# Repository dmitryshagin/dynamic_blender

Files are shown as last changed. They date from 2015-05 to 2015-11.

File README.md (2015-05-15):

# Dynamic trimix blender 
**This project includes both hardware description & all needed software and firmware.**

Blender is built to mix EAN and Trimix mixtures dynamically, with no more than 40% of oxygen.

Main electronic components:
* MCU: Atmega64. 16 or 32kB versions could be used with no/minimum code changes (untested).
* ADC: AD7793. Used to get accurate O2 readings.
* Any oxygen sensors with 7-25mV @ 21% O2 output could be used without any changes.

Software needed to work with schematic and board:
* [Eagle](http://www.cadsoftusa.com/download-eagle/) for schematic and board. Free version is enough.
* [FreeRouting](http://www.freerouting.net/) - was used for initial routing. Optional.
* [Gerbv](http://gerbv.sourceforge.net/) to preview gerbers. Optional - just to control them before factory processing.

I've ordered PCB's at [SeeedStudio](http://www.seeedstudio.com/service/index.php?r=pcb), but feel free to use any PCB factory with equivalent capabilities. Board size is 44x122mm.

Developed by [DiveTeam](http://diveteam.com.ua) :rowboat:

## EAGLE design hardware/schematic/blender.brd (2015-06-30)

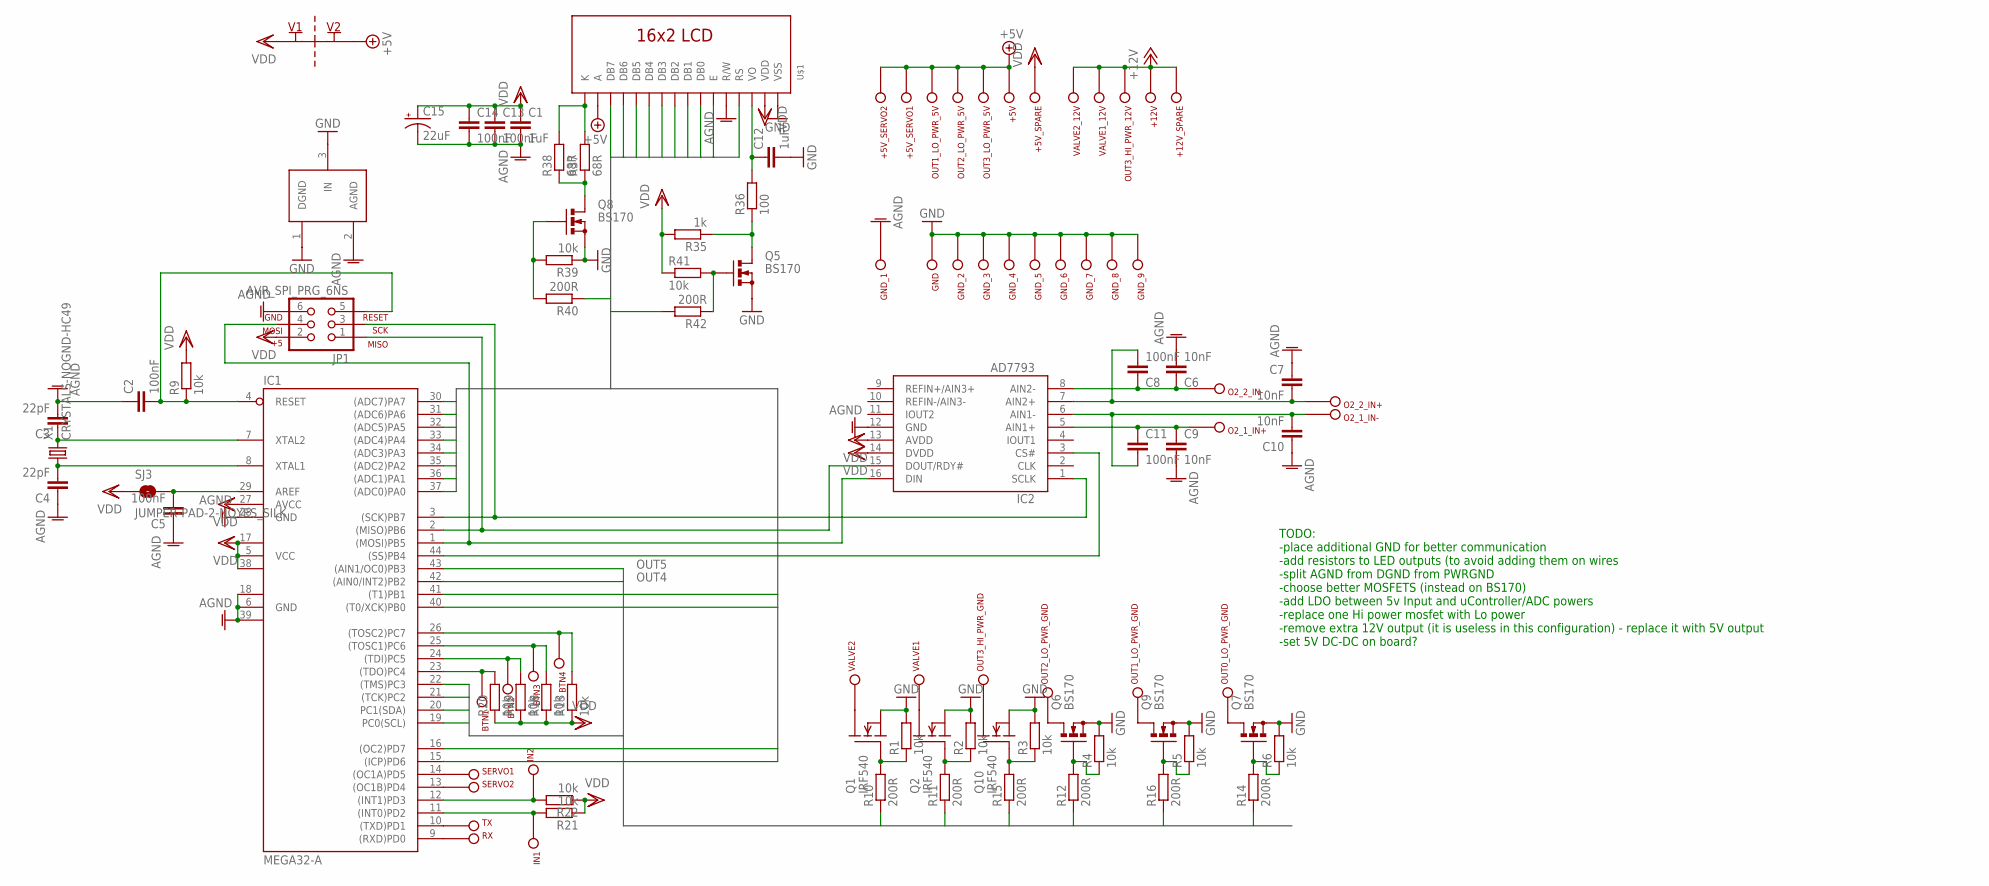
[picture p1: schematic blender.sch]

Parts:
+5V, +5V_SERVO1, +5V_SERVO2, +5V_SPARE, +12V, +12V_SPARE: PIN
BTN1, BTN2, BTN3, BTN4: PIN
C1, C12: 1uF; C0603
C2, C5, C8, C11, C13, C14: 100nF; C0603
C3, C4: 22pF; C0603
C6, C7, C9, C10: 10nF; C0603
C15: 22uF; EIA7343
GND: PIN
GND_1, GND_2, GND_3, GND_4, GND_5, GND_6, GND_7, GND_8, GND_9: PIN
IC1: MEGA32-A; TQFP44
IC2: AD7793; TSSOP16
IN1, IN2: PIN
JP1: AVR_SPI_PRG_6NS; 2X3-NS
O2_1_IN+, O2_1_IN-, O2_2_IN+, O2_2_IN-: PIN
OUT0_LO_PWR_GND, OUT1_LO_PWR_5V, OUT1_LO_PWR_GND, OUT2_LO_PWR_5V, OUT2_LO_PWR_GND, OUT3_HI_PWR_12V, OUT3_HI_PWR_GND, OUT3_LO_PWR_5V: PIN
Q1, Q2, Q10: IRF540; TO220
Q5, Q6, Q7, Q8, Q9: BS170; SOT54E
R1, R2, R3, R4, R5, R6, R9, R13, R18, R19, R20, R21, R22, R39, R41: 10k; R0603
R10, R11, R12, R14, R15, R16, R40, R42: 200R; R0603
R35: 1k; R0603
R36: 100; R0603
R37, R38: 68R; R1206
RX: PIN
SERVO1, SERVO2: PIN
SJ3: JUMPER-PAD-2-NOYES_SILK; PAD-JUMPER-2-NO_YES_SILK
TX: PIN
U$1: 1602L
U$2: SUPPLY_CONNECT; 2PT_GND_TIE
U$3: GND_CONNECT
VALVE1, VALVE1_12V, VALVE2, VALVE2_12V: PIN
X1: CRYSTALS-NOGND-HC49; HC49

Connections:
+5V: +5V.P$1, +5V_SERVO1.P$1, +5V_SERVO2.P$1, OUT1_LO_PWR_5V.P$1, OUT2_LO_PWR_5V.P$1, OUT3_LO_PWR_5V.P$1, U$1.P$15 (A), U$2.P$2
+12V: +12V.P$1, +12V_SPARE.P$1, OUT3_HI_PWR_12V.P$1, VALVE1_12V.P$1, VALVE2_12V.P$1
AGND: C1.2, C2.1, C3.2, C4.1, C5.1, C6.2, C7.1, C9.2, C10.1, C13.2, C14.2, C15.C (-), GND_1.P$1, IC1.6 (GND), IC1.18 (GND1), IC1.28 (GND), IC1.39 (GND2), IC2.12 (GND), JP1.6, U$1.P$5 (R/W), U$3.2 (AGND)
BACKLIGHT: IC1.16 ((OC2)PD7), R40.1
CONTRAST: IC1.15 ((ICP)PD6), R42.2
DB0: IC1.37 ((ADC0)PA0), U$1.P$7 (DB0)
DB1: IC1.36 ((ADC1)PA1), U$1.P$8 (DB1)
DB2: IC1.35 ((ADC2)PA2), U$1.P$9 (DB2)
DB3: IC1.34 ((ADC3)PA3), U$1.P$10 (DB3)
DB4: IC1.33 ((ADC4)PA4), U$1.P$11 (DB4)
DB5: IC1.32 ((ADC5)PA5), U$1.P$12 (DB5)
DB6: IC1.31 ((ADC6)PA6), U$1.P$13 (DB6)
DB7: IC1.30 ((ADC7)PA7), U$1.P$14 (DB7)
E: IC1.40 ((T0/XCK)PB0), U$1.P$6 (E)
GND: C12.2, GND.P$1, GND_2.P$1, GND_3.P$1, GND_4.P$1, GND_5.P$1, GND_6.P$1, GND_7.P$1, GND_8.P$1, GND_9.P$1, Q1.3 (S), Q2.3 (S), Q5.S, Q6.S, Q7.S, Q8.S, Q9.S, Q10.3 (S), R1.2, R2.2, R3.2, R4.2, R5.2, R6.2, R39.1, U$1.P$1 (VSS), U$3.1 (DGND), U$3.3 (IN)
unnamed: Q5.D, R35.1, R36.1
unnamed: C12.1, R36.2, U$1.P$3 (VO)
unnamed: Q8.D, R37.1, R38.1
unnamed: R37.2, R38.2, U$1.P$16 (K)
unnamed: Q8.G, R39.2, R40.2
unnamed: IC1.1 ((MOSI)PB5), IC2.16 (DIN), JP1.4
unnamed: IC1.2 ((MISO)PB6), IC2.15 (DOUT/RDY#), JP1.1
unnamed: IC1.3 ((SCK)PB7), IC2.1 (SCLK), JP1.3
unnamed: IC1.44 ((SS)PB4), IC2.3 (CS#)
unnamed: C2.2, IC1.4 (RESET), JP1.5, R9.1
unnamed: Q5.G, R41.2, R42.1
unnamed: C3.1, IC1.7 (XTAL2), X1.2
unnamed: C4.2, IC1.8 (XTAL1), X1.1
unnamed: Q1.1 (G), R1.1, R10.2
unnamed: Q2.1 (G), R2.1, R11.2
unnamed: Q10.1 (G), R3.1, R15.2
unnamed: BTN3.P$1, IC1.25 ((TOSC1)PC6), R18.2
unnamed: Q7.G, R6.1, R14.2
unnamed: Q6.G, R4.1, R12.2
unnamed: Q9.G, R5.1, R16.2
unnamed: C5.2, IC1.29 (AREF), SJ3.2
unnamed: IC1.12 ((INT1)PD3), IN2.P$1, R22.2
unnamed: IC1.11 ((INT0)PD2), IN1.P$1, R21.2
unnamed: BTN4.P$1, IC1.26 ((TOSC2)PC7), R13.2
unnamed: BTN2.P$1, IC1.24 ((TDI)PC5), R19.2
unnamed: BTN1.P$1, IC1.23 ((TDO)PC4), R20.2
unnamed: IC1.9 ((RXD)PD0), RX.P$1
unnamed: IC1.10 ((TXD)PD1), TX.P$1
unnamed: IC1.14 ((OC1A)PD5), SERVO1.P$1
unnamed: IC1.13 ((OC1B)PD4), SERVO2.P$1
unnamed: Q2.2 (D), VALVE1.P$1
unnamed: Q1.2 (D), VALVE2.P$1
unnamed: OUT3_HI_PWR_GND.P$1, Q10.2 (D)
unnamed: OUT0_LO_PWR_GND.P$1, Q7.D
unnamed: OUT1_LO_PWR_GND.P$1, Q9.D
unnamed: OUT2_LO_PWR_GND.P$1, Q6.D
unnamed: C10.2, C11.2, IC2.6 (AIN1-), O2_1_IN-.P$1
unnamed: C7.2, C8.2, IC2.7 (AIN2+), O2_2_IN+.P$1
unnamed: C6.1, C8.1, IC2.8 (AIN2-), O2_2_IN-.P$1
unnamed: C9.1, C11.1, IC2.5 (AIN1+), O2_1_IN+.P$1
OUT0: IC1.19 (PC0(SCL)), R14.1
OUT1: IC1.20 (PC1(SDA)), R16.1
OUT2: IC1.21 ((TCK)PC2), R12.1
OUT3: IC1.22 ((TMS)PC3), R15.1
OUT4: IC1.42 ((AIN0/INT2)PB2), R11.1
OUT5: IC1.43 ((AIN1/OC0)PB3), R10.1
RS: IC1.41 ((T1)PB1), U$1.P$4 (RS)
VDD: +5V_SPARE.P$1, C1.1, C13.1, C14.1, C15.A (+), IC1.5 (VCC), IC1.17 (VCC1), IC1.27 (AVCC), IC1.38 (VCC2), IC2.13 (AVDD), IC2.14 (DVDD), JP1.2, R9.2, R13.1, R18.1, R19.1, R20.1, R21.1, R22.1, R35.2, R41.1, SJ3.1, U$1.P$2 (VDD), U$2.P$1

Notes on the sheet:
TODO: -place additional GND for better communication -add resistors to LED outputs (to avoid adding them on wires -split AGND from DGND from PWRGND -choose better MOSFETS (instead on BS170) -add LDO between 5v Input and uController/ADC powers -replace one Hi power mosfet with Lo power -remove extra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

Board: 2 copper layers, 100 parts (44 on the bottom side), 63 nets, no tracks yet.

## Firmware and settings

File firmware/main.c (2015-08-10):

#include "adc.h"
#include "init.h"
#include "menu.h"
#include "uart_proto.h"

int main(void){
	init();	
    
	for(;;){
		process_uart();
        process_adc_data(); 
	    process_menu_selection();

		if(need_input()){
			process_menu_internal();
			reset_need_input();
		}

		if( current_working_mode != MODE_EMERGENCY ){
        	process_alert();
        }
    }
    return 0;
}

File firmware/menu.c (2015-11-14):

#include "menu.h"
#include <stdio.h>
#include <string.h>
#include <avr/io.h>
#include <util/delay.h>
#include "init.h"
#include "lcd.h"


uint8_t mixing_submenu, mode_setup_iteration, valve1_test, valve2_test;
int8_t submenu_position = -1;
int8_t last_submenu_position = -1;

volatile uint16_t current_timer_mark = 0;
volatile uint8_t countdown_timer = 0;


void set_countdown_timer(uint8_t seconds){
    current_timer_mark = get_uptime_seconds()+seconds;
}

uint8_t get_seconds_left(){
    if( current_timer_mark > get_uptime_seconds()){
        return current_timer_mark - get_uptime_seconds();
    }else{
        return 0;
    }
}


void process_buttons()
{
    if(BUTTON_PLUS_PRESSED){
        if(buttons.buttonPlus < 0xFF){
            buttons.buttonPlus+=0xF;
        }
    }else{
        buttons.buttonPlus=0;
    }
    if(BUTTON_MINUS_PRESSED){
        if(buttons.buttonMinus < 0xFF){
            buttons.buttonMinus+=0xF;
        }
    }else{
        buttons.buttonMinus=0;
    }
}

void show_run_test(){
    submenu_position = 5; //to work with UART correctly
    last_submenu_position = 5;
    current_working_mode = MODE_RUN_TEST;
    VALVE1_OFF;
    VALVE2_OFF;
    LED_VAVLE1_OFF;
    LED_VAVLE2_OFF;
    LCDGotoXY(0,0);
    LCDstring((uint8_t *)"    Run Test   >",16);
    LCDGotoXY(0,1);
    LCDstring((uint8_t *)"                ",16);
}

void show_start_calibrate(){
    current_working_mode = MODE_START_CALIBRATE;
    VALVE1_OFF;
    VALVE2_OFF;
    LED_VAVLE1_OFF;
    LED_VAVLE2_OFF;
    LCDGotoXY(0,0);
    LCDstring((uint8_t *)"   Calibrate   >",16);
    LCDGotoXY(0,1);
    LCDstring((uint8_t *)"                ",16);    
}

void show_set_o2(){
    current_working_mode = MODE_SET_O2;
    VALVE1_OFF;
    VALVE2_OFF;
    LED_VAVLE1_OFF;
    LED_VAVLE2_OFF;
    set_alert(0,0);
    set_servo(SERVO1, 0);
    set_servo(SERVO2, 0);
    LCDGotoXY(0,0);
    LCDstring((uint8_t *)"O2<  Oxygen    +",16);
    LCDGotoXY(0,1);
    LCDstring((uint8_t *)"He             -",16);
}

void show_set_he(){
    current_working_mode = MODE_SET_HE;
    VALVE1_OFF;
    VALVE2_OFF;
    LED_VAVLE1_OFF;
    LED_VAVLE2_OFF;
    LCDGotoXY(0,0);
    LCDstring((uint8_t *)"O2   Helium    +",16);
    LCDGotoXY(0,1);
    LCDstring((uint8_t *)"He<            -",16);
}

void show_set_brightness(){
    current_working_mode = MODE_SET_BRIGHTNESS;
    VALVE1_OFF;
    VALVE2_OFF;
    LED_VAVLE1_OFF;
    LED_VAVLE2_OFF; 
    LCDGotoXY(0,0);
    LCDstring((uint8_t *)"  Brightness   +",16);
    LCDGotoXY(0,1);
    LCDstring((uint8_t *)"               -",16);
}

void show_set_contrast(){
    current_working_mode = MODE_SET_CONTRAST;
    VALVE1_OFF;
    VALVE2_OFF;
    LED_VAVLE1_OFF;
    LED_VAVLE2_OFF;
    LCDGotoXY(0,0);
    LCDstring((uint8_t *)"    Contrast   +",16);
    LCDGotoXY(0,1);
    LCDstring((uint8_t *)"               -",16);
}

void show_set_emergency_level(){
    current_working_mode = MODE_SET_EMERGENCY_LEVEL;
    VALVE1_OFF;
    VALVE2_OFF;
    LED_VAVLE1_OFF;
    LED_VAVLE2_OFF;
    LCDGotoXY(0,0);
    LCDstring((uint8_t *)"  Emergency O2 +",16);
    LCDGotoXY(0,1);
    LCDstring((uint8_t *)"               -",16);
}

void show_set_valve1(){
    current_working_mode = MODE_SET_VALVE1;
    VALVE1_ON;
    VALVE2_OFF;
    LED_VAVLE1_ON;
    LED_VAVLE2_OFF;
    LCDGotoXY(0,0);
    LCDstring((uint8_t *)"  Set O2 valve +",16);
    LCDGotoXY(0,1);
    LCDstring((uint8_t *)"               -",16);
}

void show_set_valve2(){
    current_working_mode = MODE_SET_VALVE2;
    VALVE1_OFF;
    VALVE2_ON;
    LED_VAVLE1_OFF;
    LED_VAVLE2_ON;
    LCDGotoXY(0,0);
    LCDstring((uint8_t *)"  Set He valve +",16);
    LCDGotoXY(0,1);
    LCDstring((uint8_t *)"               -",16);
}

void show_set_pid(uint8_t show_max_value){
    current_working_mode = MODE_SET_PID;
    VALVE1_OFF;
    VALVE2_OFF;
    LED_VAVLE1_OFF;
    LED_VAVLE2_OFF; 
    LCDGotoXY(0,0);
    if(show_max_value){
        LCDstring((uint8_t *)"PID setup MAX  +",16);
    }else{
        LCDstring((uint8_t *)"PID setup x128 +",16);    
    }
    LCDGotoXY(0,1);
    LCDstring((uint8_t *)"               -",16);
}

void show_set_servo1_min(){
    current_working_mode = MODE_SET_SERVO1_MIN;
    VALVE1_ON;
    VALVE2_OFF;
    LED_VAVLE1_ON;
    LED_VAVLE2_OFF; 
    LCDGotoXY(0,0);
    LCDstring((uint8_t *)"  Servo1 MIN   +",16);
    LCDGotoXY(0,1);
    LCDstring((uint8_t *)"               -",16);
}

void show_set_servo1_max(){
    current_working_mode = MODE_SET_SERVO1_MAX;
    VALVE1_ON;
    VALVE2_OFF;
    LED_VAVLE1_ON;
    LED_VAVLE2_OFF; 
    LCDGotoXY(0,0);
    LCDstring((uint8_t *)"  Servo1 MAX   +",16);
    LCDGotoXY(0,1);
    LCDstring((uint8_t *)"               -",16);
}

void show_set_servo2_min(){
    current_working_mode = MODE_SET_SERVO2_MIN;
    VALVE1_OFF;
    VALVE2_ON;
    LED_VAVLE1_OFF;
    LED_VAVLE2_ON; 
    LCDGotoXY(0,0);
    LCDstring((uint8_t *)"  Servo2 MIN   +",16);
    LCDGotoXY(0,1);
    LCDstring((uint8_t *)"               -",16);
}

void show_set_servo2_max(){
    current_working_mode = MODE_SET_SERVO2_MAX;
    VALVE1_OFF;
    VALVE2_ON;
    LED_VAVLE1_OFF;
    LED_VAVLE2_ON; 
    LCDGotoXY(0,0);
    LCDstring((uint8_t *)"  Servo2 MAX   +",16);
    LCDGotoXY(0,1);
    LCDstring((uint8_t *)"               -",16);
}

void show_set_timer1(){
    current_working_mode = MODE_SET_TIMER1;
    VALVE1_OFF;
    VALVE2_OFF;
    LED_VAVLE1_OFF;
    LED_VAVLE2_OFF; 
    LCDGotoXY(0,0);
    LCDstring((uint8_t *)"    Timer1     +",16);
    LCDGotoXY(0,1);
    LCDstring((uint8_t *)"               -",16);
}
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

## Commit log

2015-05-15 Initial commit - added first version of hardware
    [blender.GBL, blender.GBO, blender.GBP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]
2015-05-30 initial firmware setup (just checked peripherial devices)
2015-06-05 Added PID, UART, EEPROM libraries. Some refactoring
2015-06-30 buttons - conect
2015-06-30 some tweaks for schematic (board destroyed), added TODOs for sch (inside sch)
    [blender.brd, blender.sch]
2015-07-28 pre-alpha release - ready to setup PID
2015-07-29 extended valved from 0-100 to 0-255
2015-07-30 bugfix - changed o2 value after calibration
    [menu.c]
2015-08-06 PID started to work
2015-08-07 PID some tuning
2015-08-09 moved PID to EEPROM
2015-08-09 added PID setup to menu
2015-08-09 first reply to uart
2015-08-10 added timer config to lcd menu (untested)
2015-08-10 added UART comunication. untested
2015-08-10 moved uart output to progmem. we are now fitting to mega32 again. mega16 is pretty much unreachable without serious refactoring
2015-08-11 added uart
2015-08-11 tested UART
2015-08-12 changed servo max setup
2015-08-13 added pid limit to config
2015-08-21 set calibration to first screen, added max value setup for PID
2015-09-22 Added display of resulting mix with decimal points. Doubled PID input resolution
2015-09-22 Added some rounding for better accuracy (PID setup with maximum 0.025% error)
    [adc.c]

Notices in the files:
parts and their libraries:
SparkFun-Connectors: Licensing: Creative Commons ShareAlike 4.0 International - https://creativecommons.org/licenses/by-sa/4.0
